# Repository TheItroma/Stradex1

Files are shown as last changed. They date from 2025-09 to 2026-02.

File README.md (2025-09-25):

STRADEX1
==============
An electronic instrument crossover between a violin, a mandolin and an otamatone

Strandex1

I've always wanted to put my violin skills to use in a MIDI environment, but there really isn't a controller on the market that can emulate the feel of a violin to the extent that Stradex does. 

Stradex features a SoftPot linear resistor to emulate the violin/mandolin fingerboard, four custom force-sensitive keys to emulate the strings, and three potentiometers for range & modulation control. This setup allows Stradex to generate pitch bends, vibrato, dynamic expression, and incredible range, all while remaining intuitive for the average string player. 

This project took me a good while. Sure, there was a lot of time spent fiddling with faulty ADS1115 chips and iterating on key designs, but most of the headscratching was in the embedded firmware, namely, the MIDI signal interface. Many digital signal filtering and processing techniques had to be employed, including buffering, low-pass filtering, digital hysterisis, and numerous serial optimizations to ensure the controller intellegently decided when to send MIDI signals and when to ignore them. 

## Build guide : 

### [**Over here !**](Docs/BuildGuide.md)

If you already have quite a bit of experience or
just don't want the bloat of the beginner guide : [This is the advanced guide](Docs/AdvancedBuildGuide.md)

Check out my website for more projects + contact me.

[My Website](https://bradylin.com/)

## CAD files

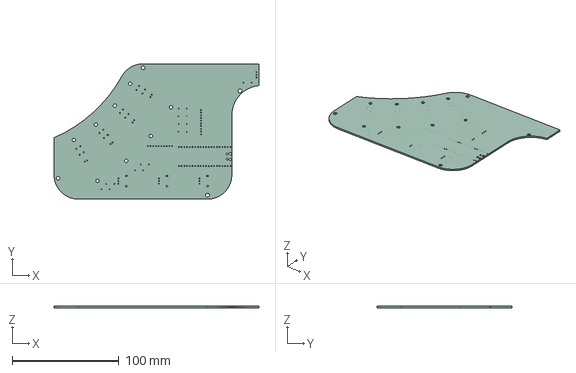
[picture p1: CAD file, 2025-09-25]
3DFiles/OriginalFiles/Cover.step
192.1 x 126.9 x 1.51 mm

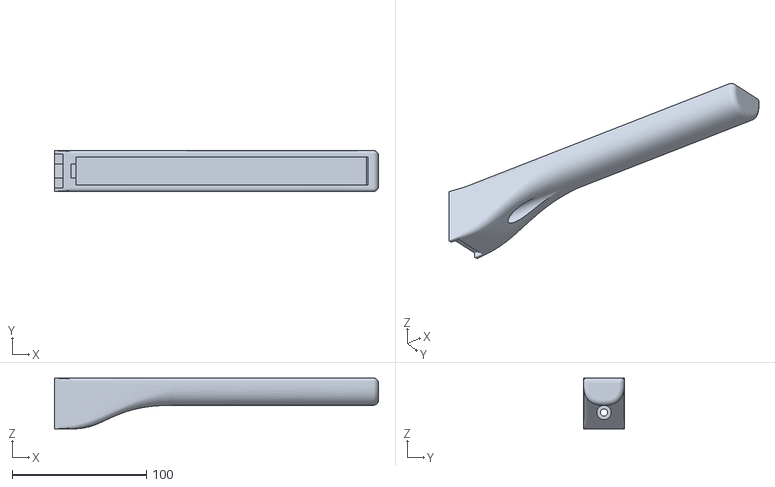
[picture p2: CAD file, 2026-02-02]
3DFiles/StlConverted/NECK(1).stl
241.3 x 30.5 x 38.0

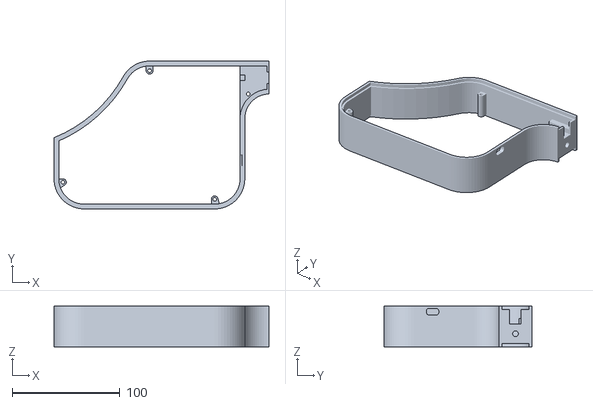
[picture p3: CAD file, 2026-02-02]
3DFiles/StlConverted/BODY(1).stl
199.3 x 137.0 x 38.0

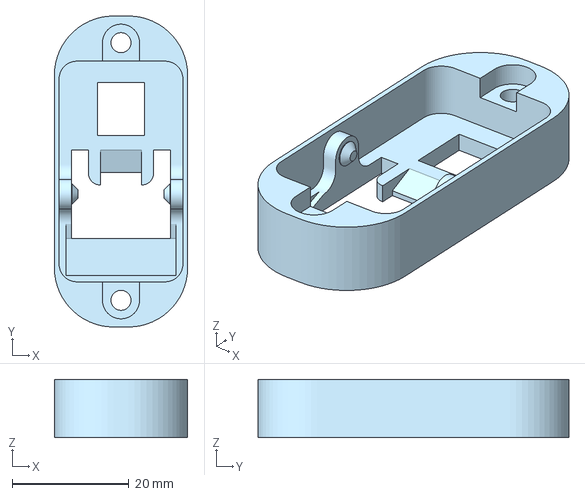
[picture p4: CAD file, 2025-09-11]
3DFiles/OriginalFiles/HINGE(4).3mf
22.9 x 53.3 x 10.0 mm

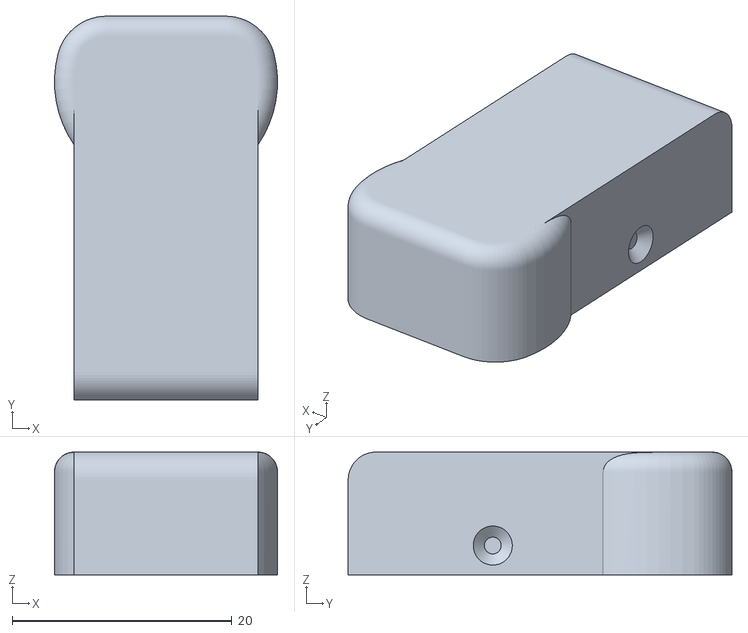
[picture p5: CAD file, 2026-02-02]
3DFiles/StlConverted/KEY(4).stl
20.3 x 34.9 x 11.2

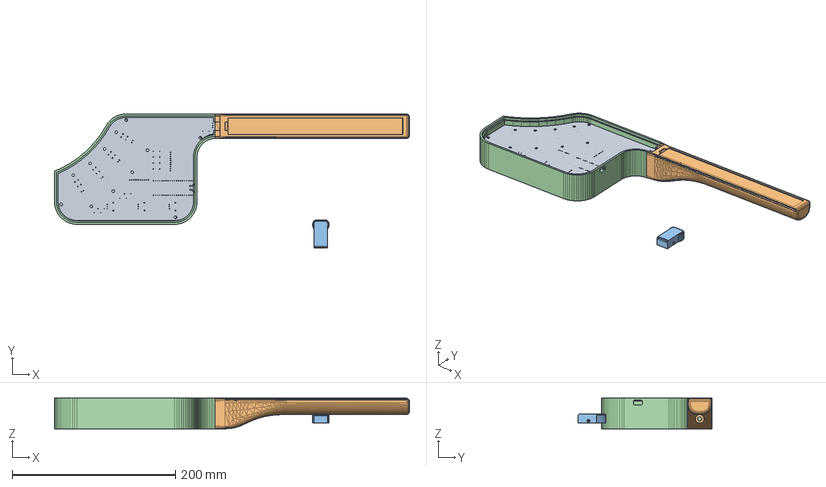
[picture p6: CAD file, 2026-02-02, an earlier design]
3DFiles/ProjectFiles/Deprecated.FCStd
434.9 x 164.3 x 37.5 mm
Plate001
Neck001
Key001

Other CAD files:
3DFiles/OriginalFiles/KEY(4).3mf
3DFiles/StlConverted/HINGE(4).stl
3DFiles/OriginalFiles/NECK(1).3mf
3DFiles/OriginalFiles/BODY(1).3mf

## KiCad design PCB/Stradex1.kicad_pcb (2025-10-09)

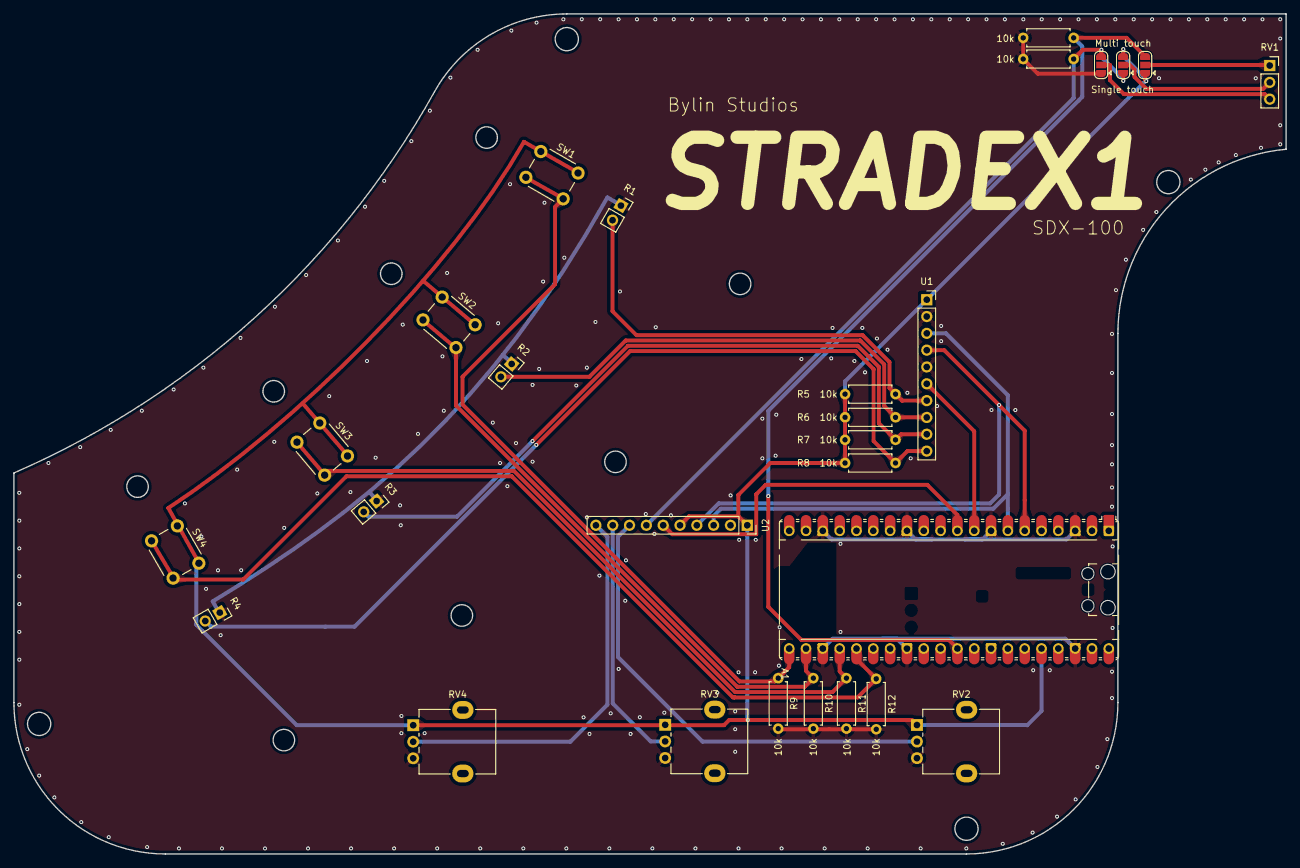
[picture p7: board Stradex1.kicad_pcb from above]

Board: 2 copper layers, 192.1 x 126.9 mm, 28 parts (0 on the bottom side), 22 nets.

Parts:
A1: RaspberryPi_Pico; RaspberryPi_Pico_Common_Unspecified
R1, R2, R3, R4: FSR; PinSocket_1x02_P2.54mm_Vertical
R5, R6, R7, R8, R9, R10, R11, R12, R13, R17: 10k; R_Axial_DIN0207_L6.3mm_D2.5mm_P7.62mm_Horizontal
RV1: SoftPot; PinSocket_1x03_P2.54mm_Vertical
RV2, RV3, RV4: R_Pot; Potentiometer_Alpha_RD901F-40-00D_Single_Vertical
SW1, SW2, SW3, SW4: SW_Push; SW_PUSH_6mm
SW5, SW6, SW7: MT_JUMPER_1; SolderJumper-3_P1.3mm_Open_RoundedPad1.0x1.5mm
U1, U2: ADS1115IDGS; PinSocket_1x10_P2.54mm_Vertical

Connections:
+3.3V: A1.36 (3V3), R5.2, R6.2, R7.2, R8.2, RV2.1, RV3.1, RV4.1, SW1.1, SW2.1, SW3.1, SW4.1, SW5.3 (C), SW7.1 (A), U1.1 (VDD), U2.1 (VDD), U2.5 (ADDR)
/ALRT1: A1.9 (GPIO6), U1.6 (ALERT/RDY)
/ALRT2: A1.10 (GPIO7), U2.6 (ALERT/RDY)
/FSR1: R1.2, R5.1, U1.7 (AIN0)
/FSR2: R2.2, R6.1, U1.8 (AIN1)
/FSR3: R3.2, R7.1, U1.9 (AIN2)
/FSR4: R4.2, R8.1, U1.10 (AIN3)
/P1: RV2.2, U2.8 (AIN1)
/P2: RV3.2, U2.9 (AIN2)
/P3: RV4.2, U2.10 (AIN3)
/PB1: A1.21 (GPIO16), R9.1, SW1.2
/PB2: A1.22 (GPIO17), R10.1, SW2.2
/PB3: A1.24 (GPIO18), R11.1, SW3.2
/PB4: A1.25 (GPIO19), R12.1, SW4.2
/SCL: A1.7 (GPIO5), U1.3 (SCL), U2.3 (SCL)
/SDA: A1.6 (GPIO4), U1.4 (SDA), U2.4 (SDA)
/SPot: R17.2, SW5.1 (A), SW6.3 (C), U2.7 (AIN0)
/SPot_MT: A1.31 (GPIO26_ADC0), R13.1, SW7.3 (C)
GND: A1.3 (GND), A1.8 (GND), A1.13 (GND), A1.18 (GND), A1.23 (GND), A1.28 (GND), A1.38 (GND), R1.1, R2.1, R3.1, R4.1, R9.2, R10.2, R11.2, R12.2, R13.2, R17.1, RV2.3, RV3.3, RV4.3, SW6.1 (A), U1.2 (GND), U1.5 (ADDR), U2.2 (GND)
unnamed: RV1.2, SW5.2 (B)
unnamed: RV1.3, SW6.2 (B)
unnamed: RV1.1, SW7.2 (B)

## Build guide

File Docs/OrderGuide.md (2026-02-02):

# Component buying guide

### Prerequisites

None! Just know that buying components for [Aliexpress](https://aliexpress.com) is the cheapest way to get electronics but sinces it often comes by boat, it will most likely take over 2 weeks to arrive. [Amazon](https://amazon.com) on the other hand, might take less than a week but is **SIGNIFICANTLY MORE EXPENSIVE**. The price estimates in the price section are very, very loose. Shopping on aliexpress is kind off an art in of itself at this point. If you wish to find cheaper parts. Here's one tip that will make it much easier : just pick "choice" items. You get free shipping if the order is over 10$ (it will be) When arriving at the cart, verify that you have all the items you need and verify each of them for shipping fees, they can slip in sometimes, be carefull. On the front of scams, I haven't encountered any yet.

### Tools

For this build, you'll need : 

- A 3d printer (I use an ender 3 pro, Very worth for the price)
- A soldering kit (Literally any cheap one will do, if you have more money, Look around for separated higher qualitie items but I don't suggest investing in good stuff since the cheap stuff will last you long and be absolutly fine. If you do want the higher quality stuff, you'll need to buy a solder wick or pump and a solder cleanning spunge or brass ball)
- Solder (**DO NOT USE THE ONE PROVIDED WITH THE KIT** from my experience, its shit (its ok if you're really on a budget but do at your own risk). I'd reccomend buying it separatly, make sure its lead free(ideally) and that it has a good % of flux - I use 2%. Also, the size should be ~ 0.5mm - 1mm)
    
Optional but nice to have : 

- Helping hand (NO NEED TO BUY, you can made ones out of laundry clips or just 3d print 1)
- Flux (idk, in case you have a solder with few of it or if u wanna make em better and prettier)

### **IF YOU'RE HESITANT ON BUYING A 3D PRINTER :**

In my oppinion, every single person on this earth should own one. For all the shitty plastic gadget you buy for whatever reason, theres an INSANE transportation pollution and monetary cost associated. Its all imported from china and NOT AT ALL space efficient. Owning a 3d printer allows you to localise the manifacturing for plastic recyclable usefull parts that you can design yourself. It allows you to repair expensive stuff that really only needs a tiny tiny plastic part to function that the manifacturer won't provide. It allows you to make a whole ass organisation system for every aspect of your life - Checkout gridfinity. If you are passionate about music making and broke, chances are buying a 300 CAD printer will allow you to make multiple instruments costing 100 CAD but as good if not more than 599 CAD consumer versions (The synth/midi community is kinda getting riped off lol).

**If you still don't want to, you can always send the parts to be printed to places [like pcbway](https://pcbway.com) or a local FAB(Fabrication places(they have 3d printers, cnc stuff, solder kits, etc... all for rent))**

### The pcb

There are 2 main platforms for ordering pcb's : jlcpcb and pcbway. From what It says online, jlcpcb.com is the better platform for pcb's. So go to jlcpcb.com, scroll down and "add gerber files" go to the folder you downloaded -> PCB -> "ThisIsTheGerber.zip". You do not need to extract it. You cannot purchase more than 5 pcb's sooo, make some for your friends or sell them or something. Here are the only settings you might want to change : PCB Color (carefull with that, the price might fluctuate per demand), Surface finish (Pick LeadFree, Its very slightly harder to solder, very slightly more expensive but doesn't contain lead so more environement friendly). Then, select your shippement option and build time and done.

**A PCB-LESS VERSION MIGHT BE DESIGNED**

### The components

You'll need :
    
| Part | Quantity for 1  | Quantity in sold package  | Notes |Price (CAD)  | Url |
| ---|---:|---:|---|----:|-----|
| Raspberry pi pico (Normally, the second one, but I think it should work with the first one as well) | 1 |  1|  Choose the version without header, also, Im pretty sure that it would work with the pico 1, will have to verify | 7.8 | https://www.pishop.ca/product/raspberry-pi-pico-2/?src=raspberrypi|
| SoftPot 200mm (SP-L-0200-103-3%-RH) | 1 | 1 | | 40 | https://www.digikey.ca/en/products/detail/spectra-symbol/SP-L-0200-103-3-RH/2175427 |
|  ADS1115 Breackout boards | 2 | 2 | | 5 | https://www.aliexpress.com/item/1005007906475242.html |
| 10K Vertical Potentiometer | 3 | 5 | | 3.70 | https://www.aliexpress.com/item/1005006220604488.html |
| 10k FSR Soft tactile pushbuttons | 4 | 100 | | 5 | https://www.aliexpress.com/item/1005009964547709.html |
| 10k FSR | 4 | 2 | It wouldn't suprise me if you could find a cheaper one for this one | 14.68 | https://www.aliexpress.com/item/1005007170243698.html
| 10k Resistors | 10 | 300 | | 5 | https://www.aliexpress.com/item/1005008321368077.html |
| M3 40mm Machine screws | 4 | 20 | | 5 | https://www.aliexpress.com/item/33003801934.html |
| Other M3 Machine screws | 20 | 392 | | 8.50 | https://www.aliexpress.com/item/1005007273134914.html |

**VERY ROUGHT ESTIMATE, YMMV, INCLUDES TAXES AND SHIPPING** Assuming you already have a 3d printer and fillament, a soldering iron and some salvaged wire or bought off aliexpress. ** If you find better pricing, please open an issue **

**Total price : ~95 CAD**

### Next step :

[**3D printing guide!**](3dPrintingGuide.md)

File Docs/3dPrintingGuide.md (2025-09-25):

# 3d Printing Guide 

### Prerequisites

You can click on each of them for a separate guide : 

- [Setup your 3d printer](https://www.youtube.com/watch?v=T-Z3GmM20JM) (if not done already)
- [Calibrate it](https://www.youtube.com/watch?v=YPAXeBuq9qU) (not nessesary but worth it if you plan on using your printer often and for other projects)

### Slicing

Open the folder you downloaded and go to the "3DFiles" subfolder.

Open [Ultimaker Cura](https://ultimaker.com/software/ultimaker-cura/#downloads), make sure you configured the settings before hand like shown in the "Setup your 3d printer" guide.

Then, modify the following settings :

- TODO

Then, for each of the following picture, replicate the placements like shown, slice it and save it to whatever name (ideally, strandex + 1, 2, 3, etc...)

TODO : BUNCH OF SCREENSHOTS

TODO : SOMETHING SOMETHING SUPPORTS

### Printing

Now just copy the sliced file to a MicroSD card, eject it and insert it into the printer and print.

### Next up : Assembly

[**Lets Go!**](Assembly.md)

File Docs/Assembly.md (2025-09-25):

# Assembly

## Prerequisites

- [Learn to solder](https://www.youtube.com/watch?v=3jAw41LRBxU) (just watch the video and you should be able to do it (I think))

## General Assembly

TODO

## Next up : Soldering and Wiring.

Did you purchase a PCB? [Yes!]() / [No!]()

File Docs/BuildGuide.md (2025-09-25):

# Build guide

## Introduction

Welcome to the Stradex1 Beginner Build Guide! A guide meant for absolute begginers who never build a FOSH (Free and Open Source Hardware) project, people who want a [parts list](OrderGuide.md) or just are missing a few details. This project is the equivalent of if a mandolin(if a guitard and violin had a baby), a violin and a otamatone had a baby.

P.S : If there are anything that seem wrong (missinformation or outated links) or that you don't understand with this guide, please, please, make an [issue](#123). Also, this guide was made by a random contributor and bassically an addapted version of the Cheapino keyboard building guide made by [Tompi](https://github.com/tompi) and claude tho I did not use ai for this one.

## Step 0 : Downloading this repository

What is a repository? A repository is, in the FOSS/FOSH world what contains all the files for the project in question.

To download it, simply click [here](https://github.com/Blyn-code/Stradex1/archive/refs/heads/main.zip) and extract the zip file wherever you want

## **How to use this guide :**

Using this guide is very simple : 

- First, we'll order the components and make sure we have the tools to make this thing
- Then, we'll 3d print the nessesary parts
- After that, assembly which is devided in 3 sections :

    1. General assembly
    2. Soldering and/or wiring
    3. Finalisation

Once you finish one section, you can go to the next step by clicking the text at the bottom.

### So first step : aquire the components and tools.

[**Lets Go!**](OrderGuide.md)

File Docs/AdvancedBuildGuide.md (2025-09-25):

# Advanced building guide

## For those who don't want the insane amount of bloat in the other one

### Bill Of Materials:

1x Raspberry Pi Pico 2
1x 8.5' SoftPot
2x ADS1115 breakout boards
3x 10k Potentiometers
4x 10k FSR
4x Soft tactile pushbuttons
10x Resistors (10k)
8x M3 18mm machine screws
4x M3 40mm machine screws
12x M3 flanged nuts

### Instructions to make it:

1. Download the 3MF files inside 3D_files and using your choice of slicer, 3D print the files
2. Download the dxf file inside SDX_plates and lazer cut out of 1/8' acrylic, or extrude them by 1/8' in CAD and 3D print them if you dont have access to a lazer cutter.
3. Download the SDX_gerbers files and order a PCB from a manufacturer, or make your own on a prefboard based on the schematic.
4. Assemble the PCB with through-hole components based on the footprints on the board.
5. Snap the keys onto the hinges, and screw them into the four slots on the board using the 18mm M3 screws. Make sure the FSR is bent over the button and sandwiched between the soft tactule pushbuttons and the underside of the keys.
6. Install the PCB into the body chassis, and place the two acrylic plates on both sides of the body. Then screw the four 40mm M3 screws in to secure the pieces. 
7. Download Pico C SDK and Clone SDX_midi to import as a Pico project. Flash the firmware onto the Pico 2 and it should be detectable as a MIDI device. You can also flash the SDX_sensor_USB_debugger to print all hardware sensor raw values through the serial window to make sure you got the hardware correct.

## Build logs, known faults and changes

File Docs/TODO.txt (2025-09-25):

1. Make the belgium flag out of the language graph

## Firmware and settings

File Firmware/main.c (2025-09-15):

#include <stdio.h>
#include <stdlib.h>
#include "pico/stdlib.h"
#include "hardware/i2c.h"
#include "ads1115.h"
#include "tusb.h"

////////////////////// DEFINITIONS //////////////////////
// I2C Definitions
#define I2C_PORT i2c0
#define I2C_SDA 4
#define I2C_SCL 5

// ADS1115 Addresses
#define ADS_1_ADDR 0x48
#define ADS_2_ADDR 0x49

ads1115_adc_t ads1, ads2;

// ALRT Pins
#define ADS_1_ALRT 6
#define ADS_2_ALRT 7

// Pushbutton Pins (PB)
const int PB[] = {16, 17, 18, 19};
#define NUM_PUSHBUTTONS (sizeof(PB) / sizeof(PB[0]))
#define PB_1 PB[0]
#define PB_2 PB[1] 
#define PB_3 PB[2]
#define PB_4 PB[3]

// Sensor value storage variable arrays
bool buttons[NUM_PUSHBUTTONS];
int16_t adc_values_1[4];
int16_t adc_values_2[4];

// Non-blocking ADC reading state variables
typedef struct {
    int current_channel;
    uint32_t last_switch_time;
    bool waiting_for_switch;
} adc_state_t;

adc_state_t adc1_state = {0, 0, false};
adc_state_t adc2_state = {0, 0, false};

// Current midi state variables
int16_t current_note = -1;
int16_t previous_note = -1;
int16_t current_pitchbend = 0;
int16_t current_velocity = 0;
int16_t current_volume = 127;
int16_t previous_volume = 127;
int16_t current_modulation = 0;
int16_t previous_modulation = 0;
bool note_on = false;

// Fret detection state for hysteresis
int16_t current_fret = -1;

// Tuning state variables
int16_t tuning_offsets[4] = {0, 0, 0, 0}; // Tuning offset for each string in semitones

// ADS1115 Channel Configurations
uint16_t mux_configs[4] = {
    ADS1115_MUX_SINGLE_0,
    ADS1115_MUX_SINGLE_1,
    ADS1115_MUX_SINGLE_2,
    ADS1115_MUX_SINGLE_3
};

// Fret positions array (17 values from 9000 to 26000)
int16_t fret_positions[16] = {
    13200, // 2nd fret
    14000, // 3rd fret  
    14650, // 4th fret
    15350, // 5th fret
    16150, // 6th fret
    16800, // 7th fret
    17630, // 8th fret
    18550, // 9th fret
    19300, // 10th fret
    20220, // 11th fret
    21100, // 12th fret
    21950, // 13th fret
    22850, // 14th fret
    24000, // 15th fret
    24950,  // End boundary
    26000  // End boundary
};

// Base MIDI note values for buttons (G3, D4, A4, E5)
int16_t base_notes[4] = {55, 62, 69, 76}; // G3=55, D4=62, A4=69, E5=76

// FSR to Volume mapping configuration
#define FSR_MIN_VALUE 1000    // FSR value for maximum volume
#define FSR_MAX_VALUE 22000   // FSR value for minimum volume
#define VOLUME_MAX 127        // Maximum MIDI volume (100%)
#define VOLUME_MIN 13         // Minimum MIDI volume (~10%)

// Pitch bend configuration
#define PITCHBEND_MAX_RANGE 2048   // Maximum pitch bend range (±2048 = ±2 semitones)
#define PITCHBEND_CENTER 8192      // MIDI pitch bend center value (14-bit: 0-16383)
#define SOFTPOT_DEVIATION_MAX 500  // Maximum softpot deviation from fret center for full pitch bend

// Fret detection hysteresis configuration
#define FRET_HYSTERESIS 75        // Units of hysteresis for fret switching stability

// Modulation control configuration
#define MODULATION_MIN 0          // Minimum modulation value (CC1)
#define MODULATION_MAX 127        // Maximum modulation value (CC1)

#define MIDI_EFFECT_MIN 0
#define MIDI_EFFECT_MAX 127

// Tuning control configuration  
#define TUNING_RANGE 25           // ±13 semitones (one octave up/down)
#define TUNING_CENTER_VALUE 13500 // Potentiometer center value for standard tuning
#define TUNING_MIN_VALUE 1000        // Minimum potentiometer value
#define TUNING_MAX_VALUE 26000    // Maximum potentiometer value

// Define functions
void serial_debug_print();
void init_I2C();
void init_PB();
void init_ads();
bool read_ads_channels(ads1115_adc_t *ads, int16_t *adc_values, adc_state_t *state);
void read_PB();
void interpret_midi_state();
int16_t get_fret_from_softpot(int16_t softpot_value);
void send_note_on(int16_t note);
void send_note_off(int16_t note);
int16_t fsr_to_volume(int16_t fsr_value);
void send_volume_control(int16_t volume);
int16_t calculate_pitch_bend(int16_t softpot_value, int16_t fret_position);
void send_pitch_bend(int16_t pitch_bend_value);
int16_t pot_to_tuning_offset(int16_t pot_value);
void send_modulation_control(int16_t modulation);
void send_midifx_control(int16_t midifx);

int main()
{
    ////////////////////// INITIALIZATION //////////////////////
    stdio_init_all();
    tud_init(0);

    // Initialize Push Buttons
    init_PB();

    // Initialize I2C
    init_I2C();

    // Initialize ADS1115
    // Edit contents of function to fiddle with ADS1115 settings
    init_ads();

    absolute_time_t next = make_timeout_time_ms(500);
    
    while (true) {
        tud_task(); 

        bool ads1_complete = read_ads_channels(&ads1, adc_values_1, &adc1_state);
        bool ads2_complete = read_ads_channels(&ads2, adc_values_2, &adc2_state);
        read_PB();
        
        interpret_midi_state();
        
        // Only send note if current_note has changed
        if (current_note != previous_note) {
            // Send note off for previous note if it was valid
            if (previous_note != -1) {
                send_note_off(previous_note);
            }
            // Send note on for current note if it's valid
            if (current_note != -1) {
                send_note_on(current_note);
            }
            previous_note = current_note;
        }
    }
}

void serial_debug_print() {
    printf("ADS1: A0:%5d  A1:%5d  A2:%5d  A3:%5d ", 
            adc_values_1[0], adc_values_1[1], adc_values_1[2], adc_values_1[3]);
    printf("ADS2: A0:%5d  A1:%5d  A2:%5d  A3:%5d ", 
            adc_values_2[0], adc_values_2[1], adc_values_2[2], adc_values_2[3]);
    printf("BTN: %d %d %d %d ", buttons[0], buttons[1], buttons[2], buttons[3]);
    printf("MIDI Note: %d (Note %s)\n", current_note, note_on ? "ON" : "OFF");
}

void init_I2C() {
    i2c_init(I2C_PORT, 400*1000);
    gpio_set_function(I2C_SDA, GPIO_FUNC_I2C);
    gpio_set_function(I2C_SCL, GPIO_FUNC_I2C);
    gpio_pull_up(I2C_SDA);
    gpio_pull_up(I2C_SCL);
}

void init_PB() {
    for (int i = 0; i < NUM_PUSHBUTTONS; i++) {
        gpio_init(PB[i]);
        gpio_set_dir(PB[i], GPIO_IN);
    }
}
void init_ads() {
    ads1115_init(I2C_PORT, ADS_1_ADDR, &ads1);
    ads1115_init(I2C_PORT, ADS_2_ADDR, &ads2);

    ads1115_set_pga(ADS1115_PGA_4_096, &ads1);
    ads1115_set_data_rate(ADS1115_RATE_860_SPS, &ads1);
    ads1115_set_operating_mode(ADS1115_MODE_CONTINUOUS, &ads1);
    ads1115_set_pga(ADS1115_PGA_4_096, &ads2);
    ads1115_set_data_rate(ADS1115_RATE_860_SPS, &ads2);
    ads1115_set_operating_mode(ADS1115_MODE_CONTINUOUS, &ads2);
}

void read_PB() {
    for (int i = 0; i < 4; i++) {
        buttons[i] = gpio_get(PB[i]);
    }
}

bool read_ads_channels(ads1115_adc_t *ads, int16_t *adc_values, adc_state_t *state) {
    uint32_t current_time = to_ms_since_boot(get_absolute_time());
    
    // If we're waiting for a channel switch to settle
    if (state->waiting_for_switch) {
        if (current_time - state->last_switch_time >= 3) {
            // Channel has settled, read the ADC value
            ads1115_read_adc(&adc_values[state->current_channel], ads);
            state->waiting_for_switch = false;
            state->current_channel++;
            
            // Check if we've read all channels
            if (state->current_channel >= 4) {
                state->current_channel = 0;
                return true; // All channels read
            }
        }
        return false; // Still waiting or not all channels read
    }
    
    // Set up the next channel and start waiting
    ads1115_set_input_mux(mux_configs[state->current_channel], ads);
    ads1115_write_config(ads);
    state->last_switch_time = current_time;
    state->waiting_for_switch = true;
    
    return false; // Channel switch initiated, need to wait
}

// Helper function to determine fret position from softpot value with hysteresis
int16_t get_fret_from_softpot(int16_t softpot_value) {
    // If softpot value is below minimum threshold, no fret is pressed
    if (softpot_value < fret_positions[0]) {
        current_fret = 0;
        return 0; // Open string (fret 0)
    }
    
    // Find the raw fret position without hysteresis
    int16_t raw_fret = 0;
    for (int i = 0; i < 15; i++) {
        if (softpot_value >= fret_positions[i] && softpot_value < fret_positions[i + 1]) {
            raw_fret = i + 1; // Fret number (1-16)
            break;
        }
    }
    
    // If above maximum, use highest fret
    if (raw_fret == 0) {
        raw_fret = 16;
    }
    
    // Apply hysteresis if we have a current fret
    if (current_fret != -1) {
        // Check if we're switching to an adjacent fret
        if (abs(raw_fret - current_fret) == 1) {
            // Apply hysteresis - need to cross threshold + hysteresis to switch
            int boundary_index = (raw_fret > current_fret) ? raw_fret - 1 : current_fret - 1;
            
            if (boundary_index >= 0 && boundary_index < 15) {
                int16_t threshold = fret_positions[boundary_index];
                
                if (raw_fret > current_fret) {
                    // Moving up frets - need to exceed threshold + hysteresis
                    if (softpot_value < threshold + FRET_HYSTERESIS) {
                        return current_fret; // Stay on current fret
                    }
                } else {
                    // Moving down frets - need to go below threshold - hysteresis
                    if (softpot_value > threshold - FRET_HYSTERESIS) {
                        return current_fret; // Stay on current fret
                    }
                }
            }
        }
    }
    
    // Update and return new fret
    current_fret = raw_fret;
    return raw_fret;
}

// Main function to interpret sensor data and update MIDI state
void interpret_midi_state() {
    // Reset current note
    current_note = -1;
    note_on = false;
    
    // Check which button is pressed (assuming only one at a time for monophonic)
    int pressed_button = -1;
    for (int i = 0; i < 4; i++) {
        if (buttons[i]) {
            pressed_button = i;
            break; // Take the first pressed button for monophonic behavior
        }
    }
    
    // If no button is pressed, no note should play
    if (pressed_button == -1) {
        return;
    }
    
    // Get the base note for the pressed button with tuning offset
    int16_t base_note = base_notes[pressed_button] + tuning_offsets[pressed_button];
    
    // Read FSR value for volume control based on which button is pressed
    // FSR values are on ADS1 channels 0-3 corresponding to buttons 0-3
    int16_t fsr_value = adc_values_1[pressed_button];
    
    // Convert FSR to MIDI volume and send if changed
    current_volume = fsr_to_volume(fsr_value);
    if (current_volume != previous_volume) {
        send_volume_control(current_volume);
        previous_volume = current_volume;
    }
    
    // Determine which ADC channel corresponds to the softpot for this string
    // Assuming adc_values_2[0] is the softpot for now (you may need to adjust this)
    int16_t softpot_value = adc_values_2[0];
    
    // Get fret position from softpot
    int16_t fret = get_fret_from_softpot(softpot_value);
    
    // Calculate pitch bend based on softpot deviation from fret center
    // Skip pitch bend for open strings (fret 0)
    int16_t pitch_bend = PITCHBEND_CENTER; // Default to center (no bend)
    if (fret > 0) {
        pitch_bend = calculate_pitch_bend(softpot_value, fret);
    }
    
    // Send pitch bend if changed
    if (pitch_bend != current_pitchbend) {
        send_pitch_bend(pitch_bend);
        current_pitchbend = pitch_bend;
    }
    
    // Read modulation control from ADS2 channel 2
    int16_t modulation_raw = adc_values_2[1]; // Channel 2 (0-indexed)
    current_modulation = (modulation_raw * MODULATION_MAX) / 32767; // Scale to 0-127
    if (current_modulation != previous_modulation) {
        send_modulation_control(current_modulation);
        previous_modulation = current_modulation;
    }
    
    // Read tuning control from ADS2 channel 4 and update tuning offsets
    int16_t tuning_raw = adc_values_2[3]; // Channel 4 (0-indexed)
    int16_t new_tuning_offset = pot_to_tuning_offset(tuning_raw);
    
    // Update all string tunings (could be made per-string if needed)
    for (int i = 0; i < 4; i++) {
        tuning_offsets[i] = new_tuning_offset;
    }
    
    // Calculate final MIDI note (base note + fret offset)
    current_note = base_note + fret;
    note_on = true;
}

void send_note_on(int16_t note) {
    if (!tud_midi_mounted()) return;

    const uint8_t vel = 100;
    uint8_t msg[3];
    
    msg[0] = 0x90; // Note On
    msg[1] = note;
    msg[2] = vel;
    
    tud_midi_stream_write(0, msg, 3);
}

void send_note_off(int16_t note) {
    if (!tud_midi_mounted()) return;

    uint8_t msg[3];
    
    msg[0] = 0x80; // Note Off
    msg[1] = note;
    msg[2] = 0;
    
    tud_midi_stream_write(0, msg, 3);
}

// Convert FSR value to MIDI volume (0-127)
// FSR is inverse: higher FSR values = lower volume
int16_t fsr_to_volume(int16_t fsr_value) {
    if (fsr_value < FSR_MIN_VALUE) {
        return VOLUME_MAX; // Maximum volume
    } else if (fsr_value > FSR_MAX_VALUE) {
        return VOLUME_MIN; // Minimum volume
    } else {
        // Linear interpolation between FSR_MIN_VALUE and FSR_MAX_VALUE
        // Map FSR_MIN_VALUE->VOLUME_MAX and FSR_MAX_VALUE->VOLUME_MIN
        int16_t fsr_range = FSR_MAX_VALUE - FSR_MIN_VALUE;
        int16_t fsr_offset = fsr_value - FSR_MIN_VALUE;
        int16_t volume = VOLUME_MAX - ((fsr_offset * (VOLUME_MAX - VOLUME_MIN)) / fsr_range);
        return volume;
    }
}

// Send MIDI volume control change (CC7)
void send_volume_control(int16_t volume) {
    if (!tud_midi_mounted()) return;

    uint8_t msg[3];
    
    msg[0] = 0xB0; // Control Change on channel 1
    msg[1] = 0x07; // CC7 (Main Volume)
    msg[2] = volume & 0x7F; // Ensure 7-bit value
    
    tud_midi_stream_write(0, msg, 3);
}

// Calculate pitch bend based on softpot deviation from fret center
int16_t calculate_pitch_bend(int16_t softpot_value, int16_t fret_position) {
    // Find the fret boundaries for the current fret
    int16_t fret_start, fret_end;
    
    if (fret_position == 0) {
        // Open string - use first fret as reference
        fret_start = 0;
        fret_end = fret_positions[0];
    } else if (fret_position >= 16) {
        // Beyond last fret - use last fret boundaries
        fret_start = fret_positions[15];
        fret_end = fret_positions[16];
    } else {
        // Normal fret - use current and next fret positions
        fret_start = fret_positions[fret_position - 1];
        fret_end = fret_positions[fret_position];
    }
    
    // Calculate center position between fret boundaries
    int16_t fret_center = (fret_start + fret_end) / 2;
    
    // Calculate deviation from center
    int16_t deviation = softpot_value - fret_center;
    
    // Limit deviation to maximum range
    if (deviation > SOFTPOT_DEVIATION_MAX) {
        deviation = SOFTPOT_DEVIATION_MAX;
    } else if (deviation < -SOFTPOT_DEVIATION_MAX) {
        deviation = -SOFTPOT_DEVIATION_MAX;
    }
    
    // Convert deviation to pitch bend value
    // Scale deviation to pitch bend range and add to center
    int16_t pitch_bend = PITCHBEND_CENTER + ((deviation * PITCHBEND_MAX_RANGE) / SOFTPOT_DEVIATION_MAX);
    
    return pitch_bend;
}

// Send MIDI pitch bend message
void send_pitch_bend(int16_t pitch_bend_value) {
    if (!tud_midi_mounted()) return;

    // Ensure pitch bend value is within 14-bit range (0-16383)
    if (pitch_bend_value < 0) pitch_bend_value = 0;
    if (pitch_bend_value > 16383) pitch_bend_value = 16383;
    
    uint8_t msg[3];
    
    msg[0] = 0xE0; // Pitch Bend on channel 1
    msg[1] = pitch_bend_value & 0x7F;        // LSB (7 bits)
    msg[2] = (pitch_bend_value >> 7) & 0x7F; // MSB (7 bits)
    
    tud_midi_stream_write(0, msg, 3);
}

// Convert potentiometer value to tuning offset in semitones
int16_t pot_to_tuning_offset(int16_t pot_value) {
    // Map potentiometer range to ±12 semitones
    if (pot_value < TUNING_MIN_VALUE) pot_value = TUNING_MIN_VALUE;
    if (pot_value > TUNING_MAX_VALUE) pot_value = TUNING_MAX_VALUE;
    
    // Calculate offset from center
    int32_t offset_from_center = pot_value - TUNING_CENTER_VALUE;
    
    // Scale to ±12 semitones
    int16_t tuning_offset = (offset_from_center * TUNING_RANGE) / (TUNING_MAX_VALUE / 2);
    
    // Clamp to valid range
    if (tuning_offset > TUNING_RANGE) tuning_offset = TUNING_RANGE;
    if (tuning_offset < -TUNING_RANGE) tuning_offset = -TUNING_RANGE;
    
    return tuning_offset;
}

// Send MIDI modulation control change (CC1)
void send_modulation_control(int16_t modulation) {
    if (!tud_midi_mounted()) return;

    uint8_t msg[3];
    
    msg[0] = 0xB0; // Control Change on channel 1
    msg[1] = 0x01; // CC1 (Modulation)
    msg[2] = modulation & 0x7F; // Ensure 7-bit value
    
    tud_midi_stream_write(0, msg, 3);
}

void send_midifx_control(int16_t midifx) {
    if (!tud_midi_mounted()) return;

    uint8_t msg[3];

    msg[0] = 0xB0;
    msg[1] = 0x02;
    msg[2] = midifx & 0x7F;

    tud_midi_stream_write(0, msg, 3);
}

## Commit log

2025-09-11 added readme
    [BODY(1).3mf, HINGE(4).3mf, KEY(4).3mf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]
2025-09-25 modified a few things
    [Cover.step, Stradex1.kicad_pcb, Stradex1.kicad_sch]
2025-09-25 Folder Renames
    [BODY(1).3mf, Cover.step, HINGE(4).3mf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]
2025-09-25 actual rename
    [BODY(1).3mf, Cover.step, HINGE(4).3mf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]
2025-09-28 Made the pcb 2 layers and added a gnd copper fill
    [Stradex1-B_Cu.gbr, Stradex1-B_Mask.gbr, Stradex1-B_Paste.gbr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]
2025-10-09 Stole the pcb from 'Whitebowfr'
    [Stradex1-B_Cu.gbr, Stradex1-B_Mask.gbr, Stradex1-B_Paste.gbr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]
2025-10-14 fixed bom table for fsr
2026-02-02 Im working on this again
    [BODY(1).3mf, BODY(1).stl, Cover.step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]
2026-02-02 removed duplicate file
    [Stradex1.1.FCStd]
